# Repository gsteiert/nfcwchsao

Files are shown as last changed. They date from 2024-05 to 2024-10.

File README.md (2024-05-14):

# NFCWCHSAO B4
# Beeping Blinking Badge Buddy

This board has an engergy harvesting NFC EEPROM and WCH CH32V003 MCU.  
The MCU is connected to an RGB LED and piezo buzzer.
The two ICs are 8 pin SOIC, and the passives are 0603 so it is not too dificult to hand assemble, except for the RGB LED that is a little fine pitch, but the pads are extended and the close pins are shorted together anyway so it is not too difficult.

This board is designed for and looks great in OSH Park After Dark
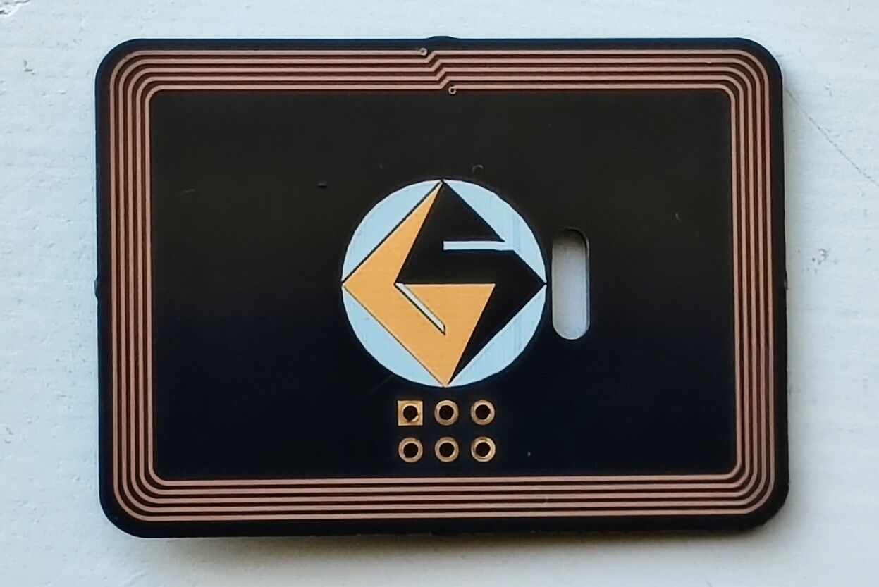
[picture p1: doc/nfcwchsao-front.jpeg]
Front view of NFCWCHSAO board

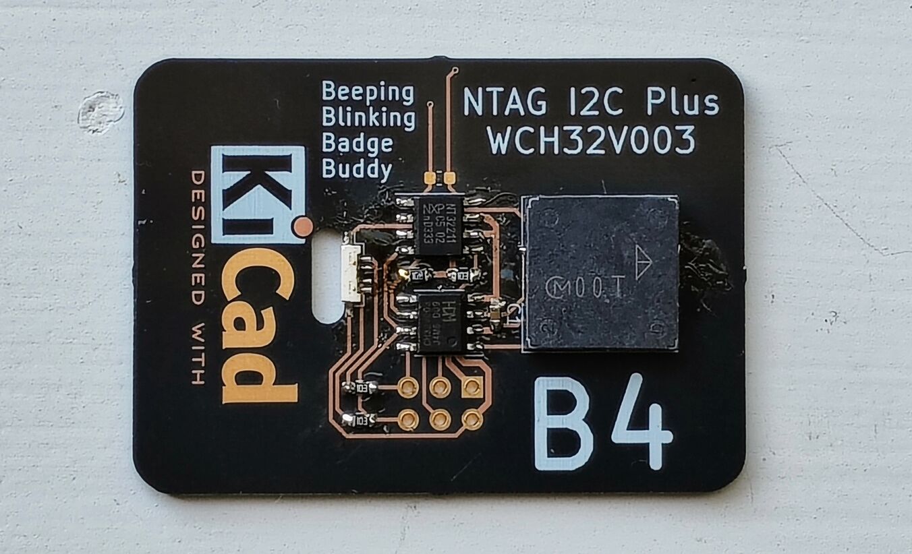
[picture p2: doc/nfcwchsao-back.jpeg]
Back view of assembled NFCWCHSAO board


[Order from OSH Park](https://oshpark.com/shared_projects/BUIwWMCI)
Be sure to choose the "After Dark" option to get the same results as in the picture.

## Components
 * [NT3H2211W0FT1X](https://www.mouser.com/ProductDetail/771-NT3H2211W0FT1X) 
 * [CH32V003J4M6](https://www.lcsc.com/product-detail/Microcontroller-Units-MCUs-MPUs-SOCs_WCH-Jiangsu-Qin-Heng-CH32V003J4M6_C5346354.html) 
 * [PKLCS1212E20A0-R1](https://www.mouser.com/ProductDetail/81-PKLCS1212E20A0-R1) 
 * [QLS6A-FKW-CNSNSF043](https://www.mouser.com/ProductDetail/941-QLS6AFKWNSNSF043) 
 * 1.0uF 0603 Capacitor
 * 4x 10K 0603 Resistors

## Schematic
[View Schematic online in KiCanvas](https://kicanvas.org/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)

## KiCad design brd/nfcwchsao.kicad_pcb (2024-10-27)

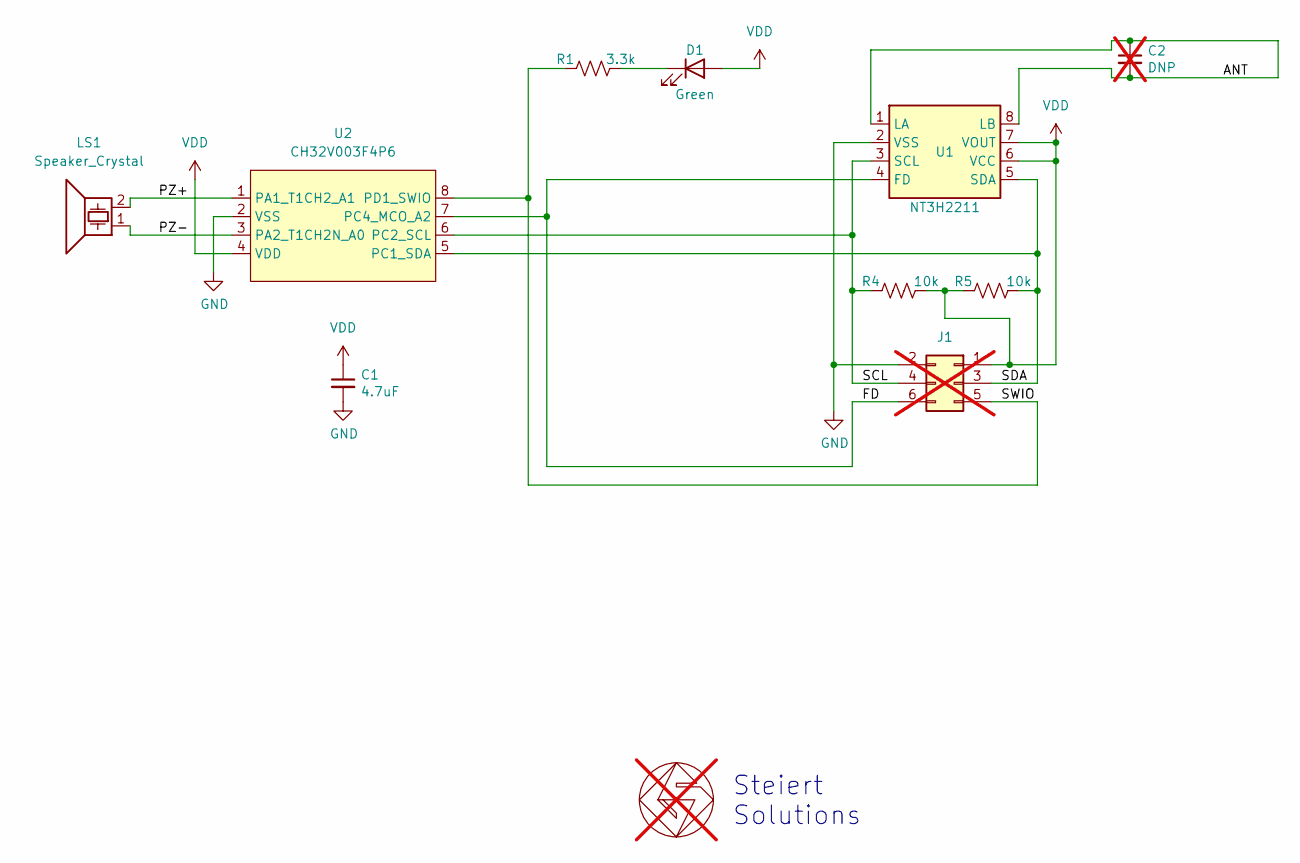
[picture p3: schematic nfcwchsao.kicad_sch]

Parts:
C1: 4.7uF; C_0603_1608Metric_Pad1.08x0.95mm_HandSolder; MPN CL10A475KP8NNNC; LCSC C1705
C2: DNP; C_0603_1608Metric; not fitted
D1: Green; LED_Right_Angle_3x2x1mm; MPN HSMG-C110; LCSC C7202185
GS1: GS_logo; gs_logo_200mil; not fitted
J1: Conn_02x03_Odd_Even; PinHeader_2x03_P2.54mm_Staggered; not fitted
LS1: Speaker_Crystal; Buzzer_Murata_PKLCS1212E_handy; MPN PKLCS1212E20A0-R1; LCSC C3811858
R1: 3.3k; R_0603_1608Metric_Pad0.98x0.95mm_HandSolder; MPN RC0603FR-073K3L; LCSC C108078
R4, R5: 10k; R_0603_1608Metric_Pad0.98x0.95mm_HandSolder; MPN RC0603FR-0710KL; LCSC C98220
U1: NT3H2211; SO-8_3.9x4.9mm_P1.27mm; MPN NT3H2211W0FT1X; LCSC C2905792
U2: CH32V003F4P6; SOP-8_3.9x4.9mm_P1.27mm; MPN CH32V003J4M6; LCSC C5346354

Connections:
/ANT: C2.1, C2.2, U1.1 (LA), U1.8 (LB)
/FD: J1.6, U1.4 (FD), U2.7 (PC4_MCO_A2)
/PZ+: LS1.2, U2.1 (PA1_T1CH2_A1)
/PZ-: LS1.1, U2.3 (PA2_T1CH2N_A0)
/SCL: J1.4, R4.2, U1.3 (SCL), U2.6 (PC2_SCL)
/SDA: J1.3, R5.1, U1.5 (SDA), U2.5 (PC1_SDA)
/SWIO: J1.5, R1.2, U2.8 (PD1_SWIO)
GND: C1.2, J1.2, U1.2 (VSS), U2.2 (VSS)
unnamed: D1.1 (K), R1.1
VDD: C1.1, D1.2 (A), J1.1, R4.1, R5.2, U1.6 (VCC), U1.7 (VOUT), U2.4 (VDD)

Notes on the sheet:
Steiert Solutions

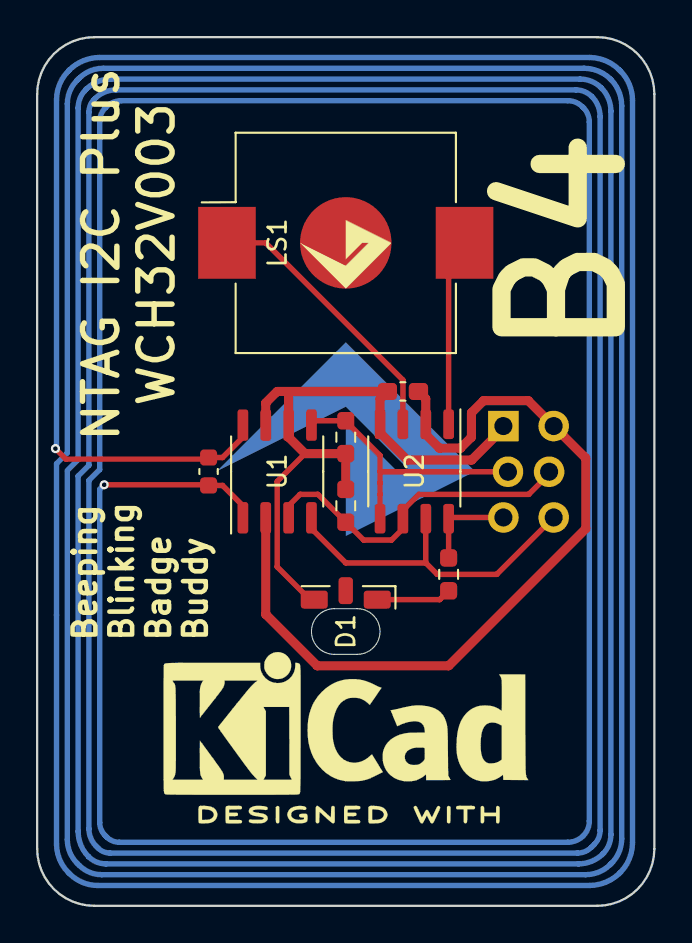
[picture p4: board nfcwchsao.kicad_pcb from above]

Board: 2 copper layers, 34.3 x 48.3 mm, 11 parts (0 on the bottom side), 10 nets.

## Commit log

2024-05-12 checking in complete design
    [nfcwchsao.kicad_pcb, nfcwchsao.kicad_sch]
2024-05-12 updating part numbers and documenation
    [nfcwchsao.kicad_sch]
2024-10-13 updating to hand solder buzzer footprint, staggered header, single color LED
    [nfcwchsao.kicad_pcb, nfcwchsao.kicad_sch]
2024-10-14 refining updates
    [nfcwchsao.kicad_pcb]
2024-10-27 cleaned up BOM, changed KiCad logo to all silkscreen
    [nfcwchsao.kicad_pcb, nfcwchsao.kicad_sch]
